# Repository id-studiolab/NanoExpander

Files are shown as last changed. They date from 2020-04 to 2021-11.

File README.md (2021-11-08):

[][cc-by]

# Nano Expander
Grove Breakout board for [Arduino Nano 33 IoT](https://store.arduino.cc/products/arduino-nano-33-iot).

This is the sibling of the [Bitsy Expander](https://github.com/id-studiolab/BitsyExpander), a Grove Breakout board for Adafruit's [ItsyBitsy M4 Express](https://www.adafruit.com/product/3800).

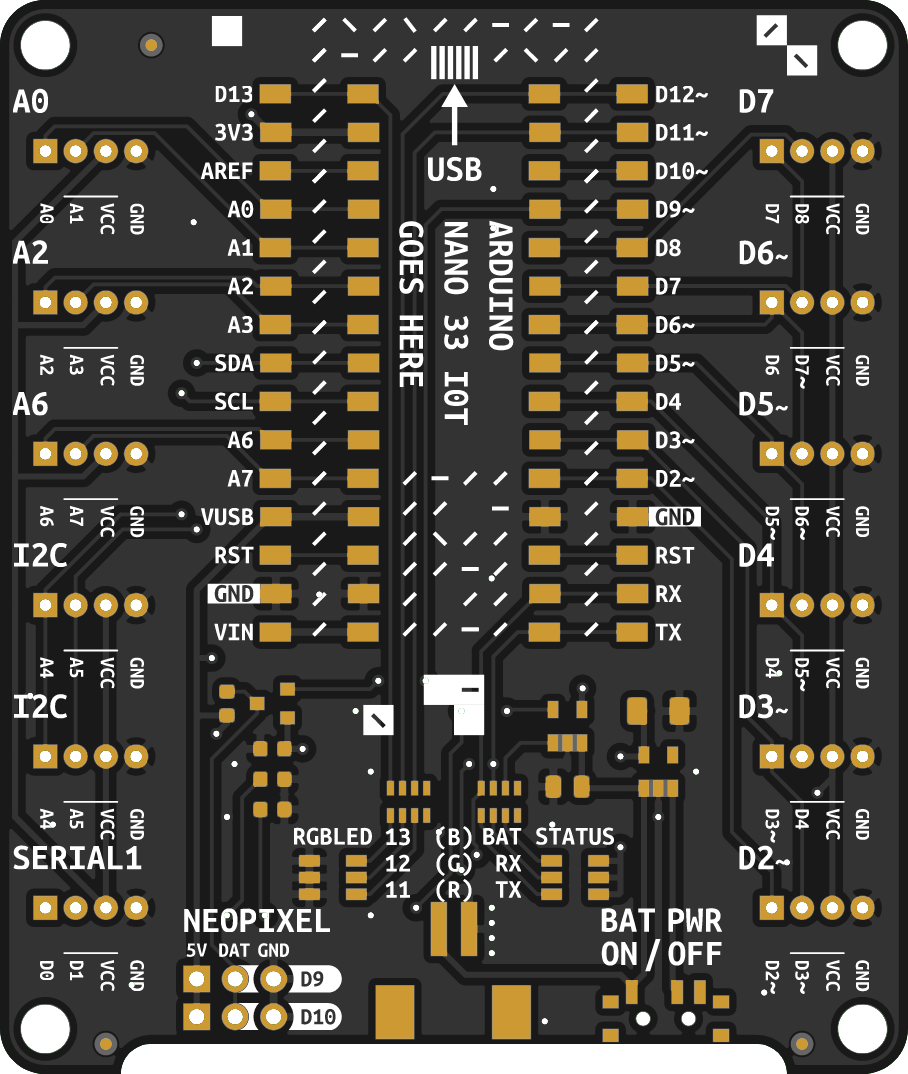
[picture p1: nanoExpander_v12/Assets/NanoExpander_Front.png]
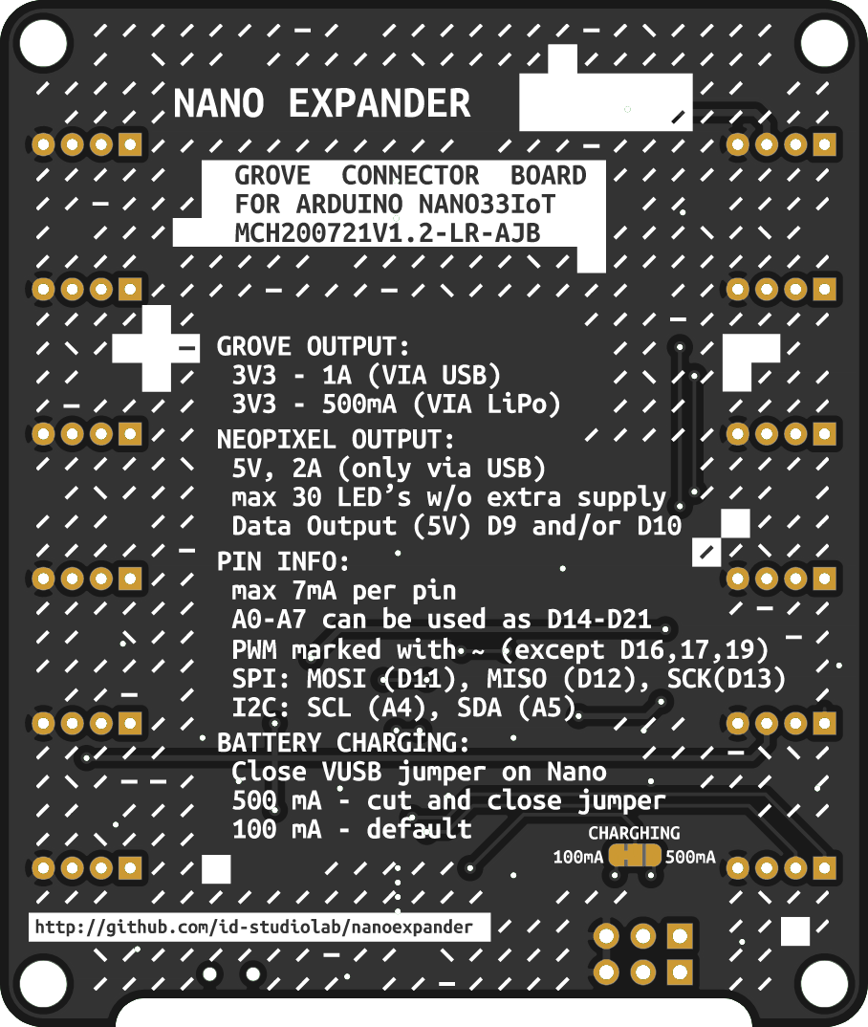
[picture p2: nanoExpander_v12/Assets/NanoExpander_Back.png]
   

This work is licensed under a
[Creative Commons Attribution 4.0 International License][cc-by].

[][cc-by]

[cc-by]: http://creativecommons.org/licenses/by/4.0/
[cc-by-image]: https://i.creativecommons.org/l/by/4.0/88x31.png
[cc-by-shield]: https://img.shields.io/badge/License-CC%20BY%204.0-lightgrey.svg

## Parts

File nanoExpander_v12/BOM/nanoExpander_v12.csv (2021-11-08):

Id | Designator | Package | Quantity | Designation | Supplier and ref
1 | U00 | ARDUINO_NANO_33_IOT_SMD_DUAL_ROW_SOCKET | 1 | ARDUINO_NANO_33_IOT
2 | REF**,REF**,REF** | Fiducial_0.75mm_Dia_1.5mm_Outer | 3 | Fiducial_0.75mm_Dia_1.5mm_Outer
3 | Q00,Q01 | SOT-23 | 2 | BSS138
4 | J13,J14 | PinSocket_1x03_P2.54mm_Vertical | 2 | Conn_01x03
5 | J05,J08,J00,J01,J02,J03,J04,J06,J07,J09,J10,J11 | NS-Tech_Grove_1x04_P2mm_Vertical | 12 | Conn_01x04
6 | C00 | C_0805_2012Metric | 1 | 10uF
7 | C01 | C_1206_3216Metric | 1 | 1uF
8 | J12 | JST_S2B-PH-SM4-TB_LARGE | 1 | Conn_01x02
9 | JP00 | SolderJumper-3_P1.3mm_Bridged12_RoundedPad1.0x1.5mm | 1 | SolderJumper_3_Bridged12
10 | R00,R02,R03 | R_0603_1608Metric | 3 | 10K
11 | R01 | R_0603_1608Metric | 1 | 2K
12 | RN00,RN01 | CAY16-J4 | 2 | 220R
13 | SW00 | SW_SPDT_PCM12 | 1 | ON/OFF
14 | U01 | SOT-23-5 | 1 | MCP73831-2
15 | U03 | SOT-23-5 | 1 | MIC5216
16 | H00,H01,H02,H03 | MountingHole_3.2mm_M3 | 4 | MountingHole
17 | C02,C03 | C_0603_1608Metric | 2 | 100nF
18 | D00,D01 | LED_RGB_PLCC-6 | 2 | LED_BGR

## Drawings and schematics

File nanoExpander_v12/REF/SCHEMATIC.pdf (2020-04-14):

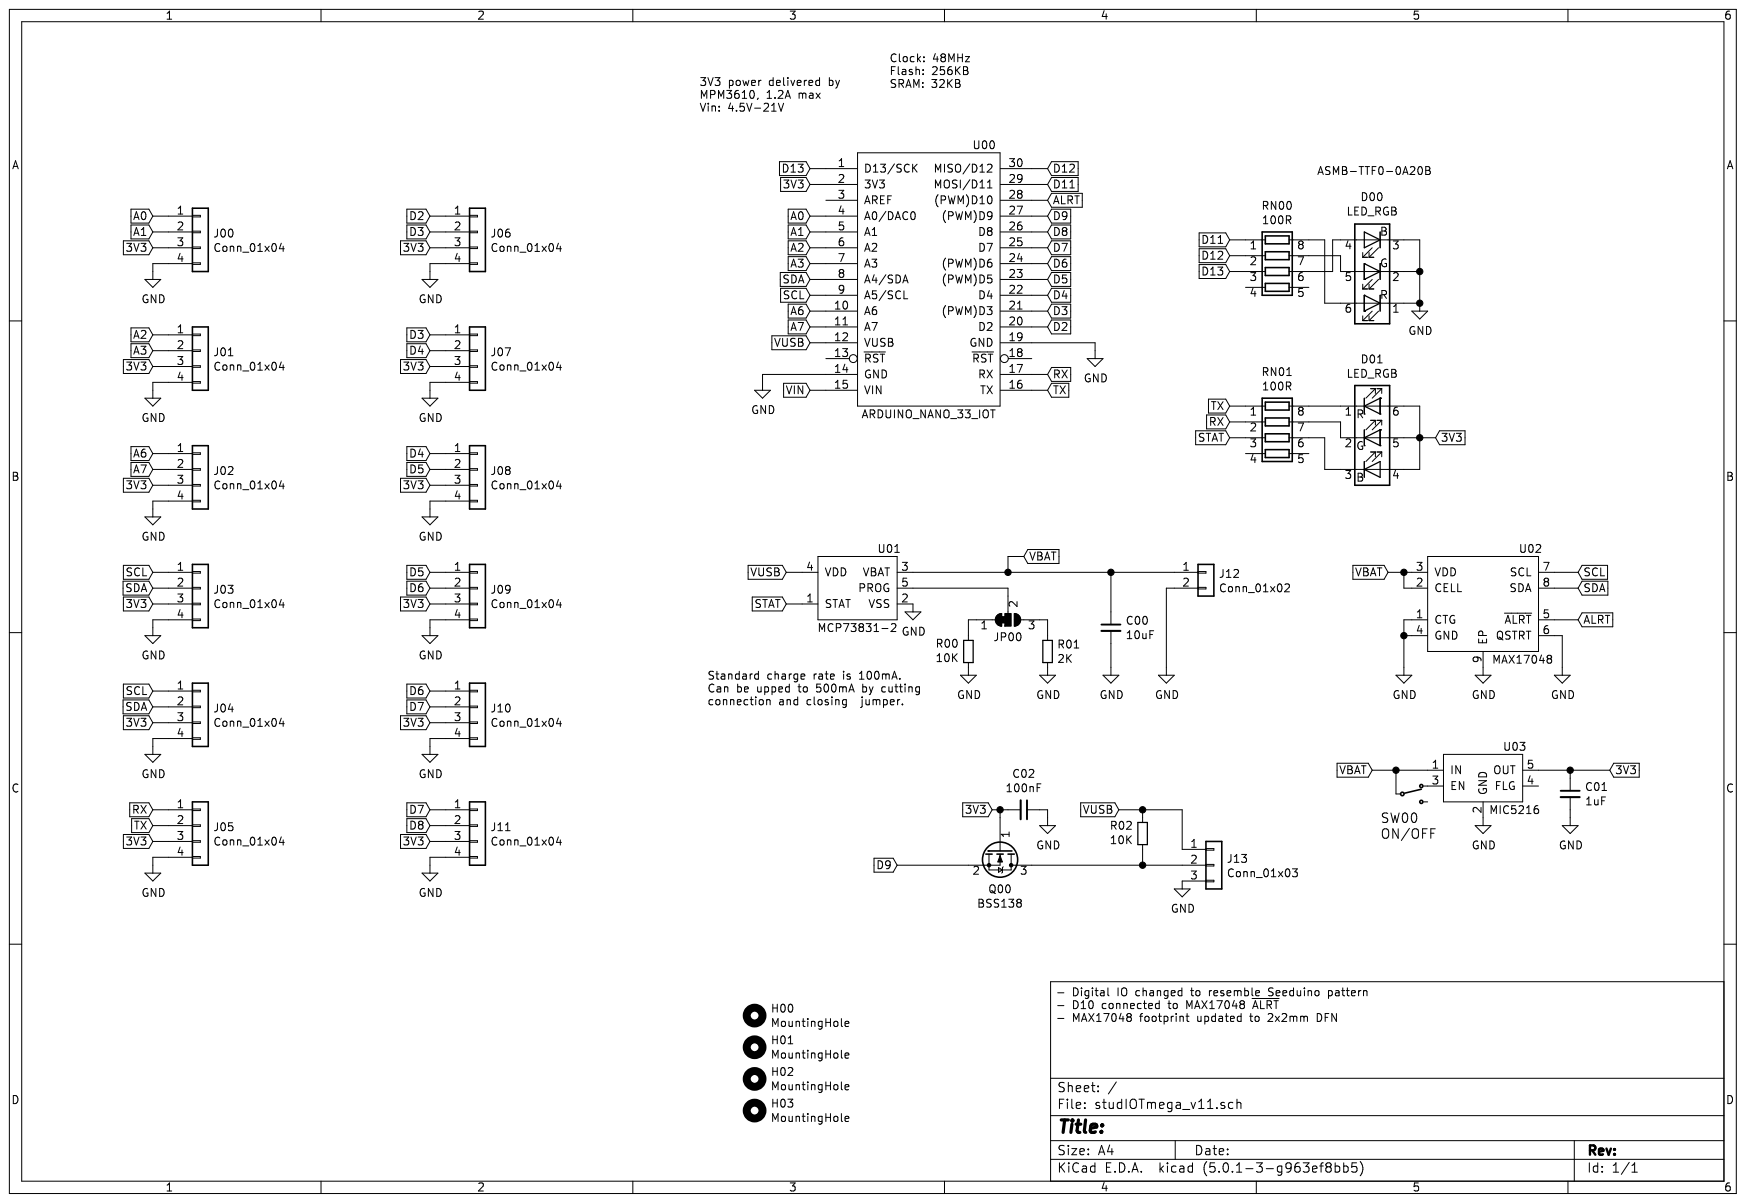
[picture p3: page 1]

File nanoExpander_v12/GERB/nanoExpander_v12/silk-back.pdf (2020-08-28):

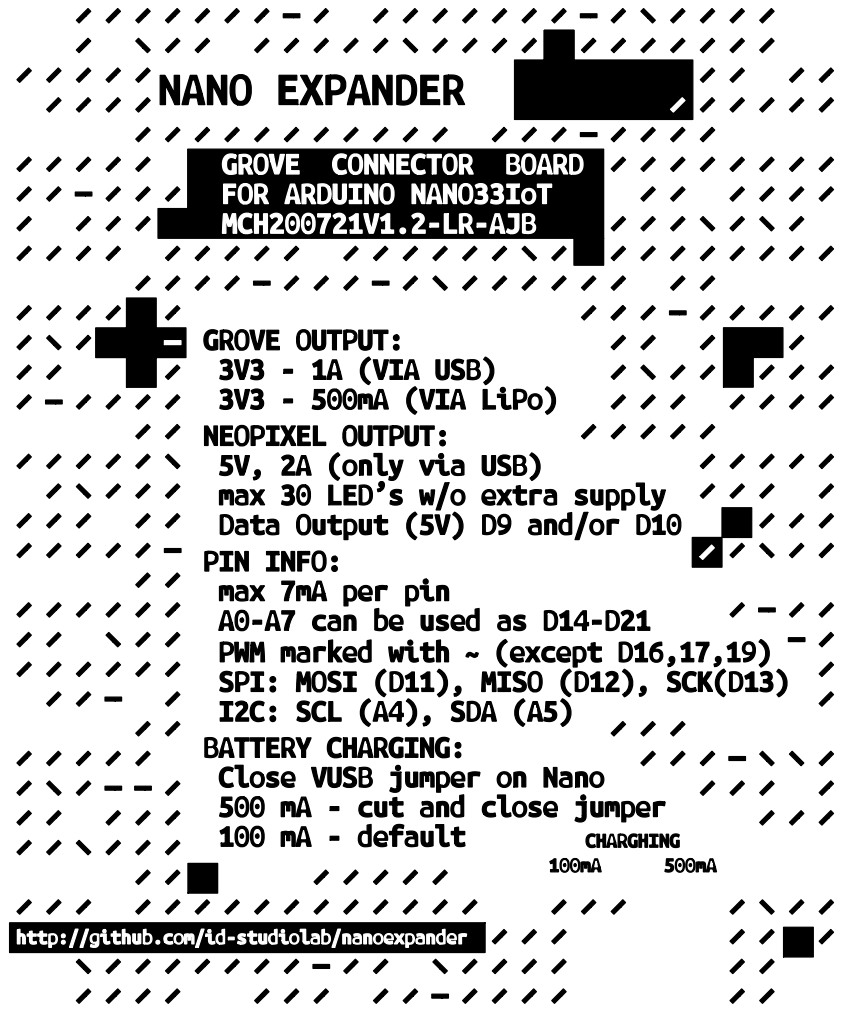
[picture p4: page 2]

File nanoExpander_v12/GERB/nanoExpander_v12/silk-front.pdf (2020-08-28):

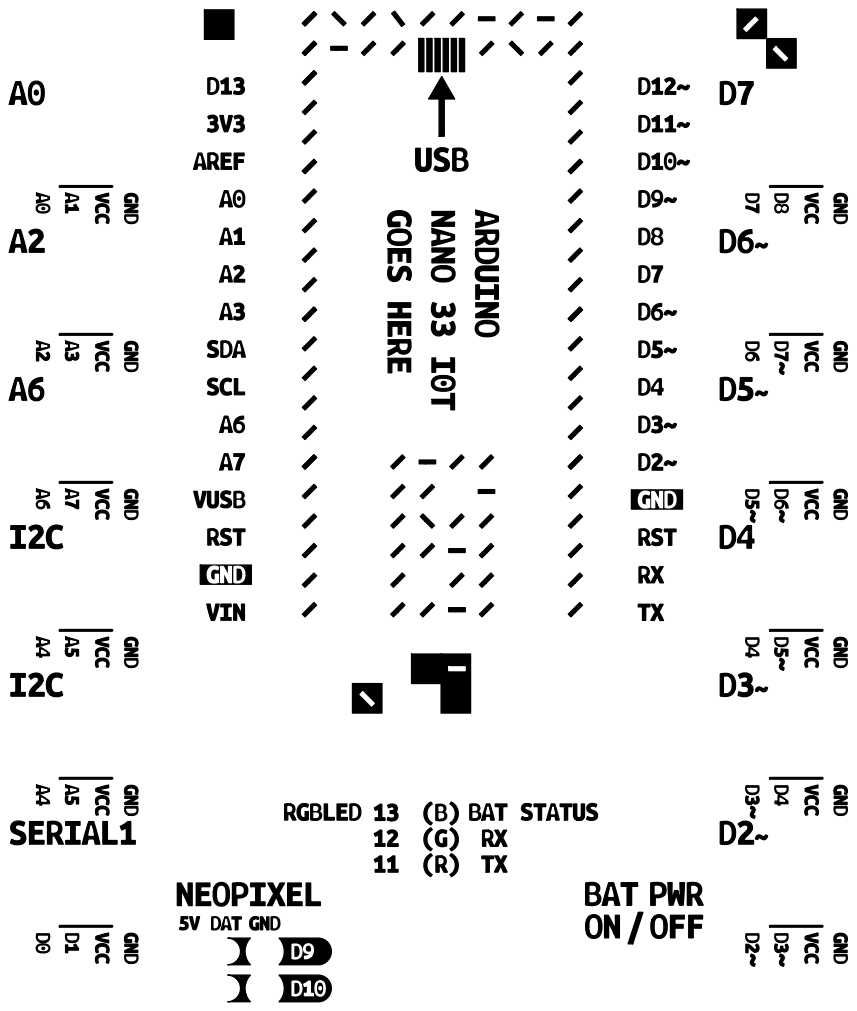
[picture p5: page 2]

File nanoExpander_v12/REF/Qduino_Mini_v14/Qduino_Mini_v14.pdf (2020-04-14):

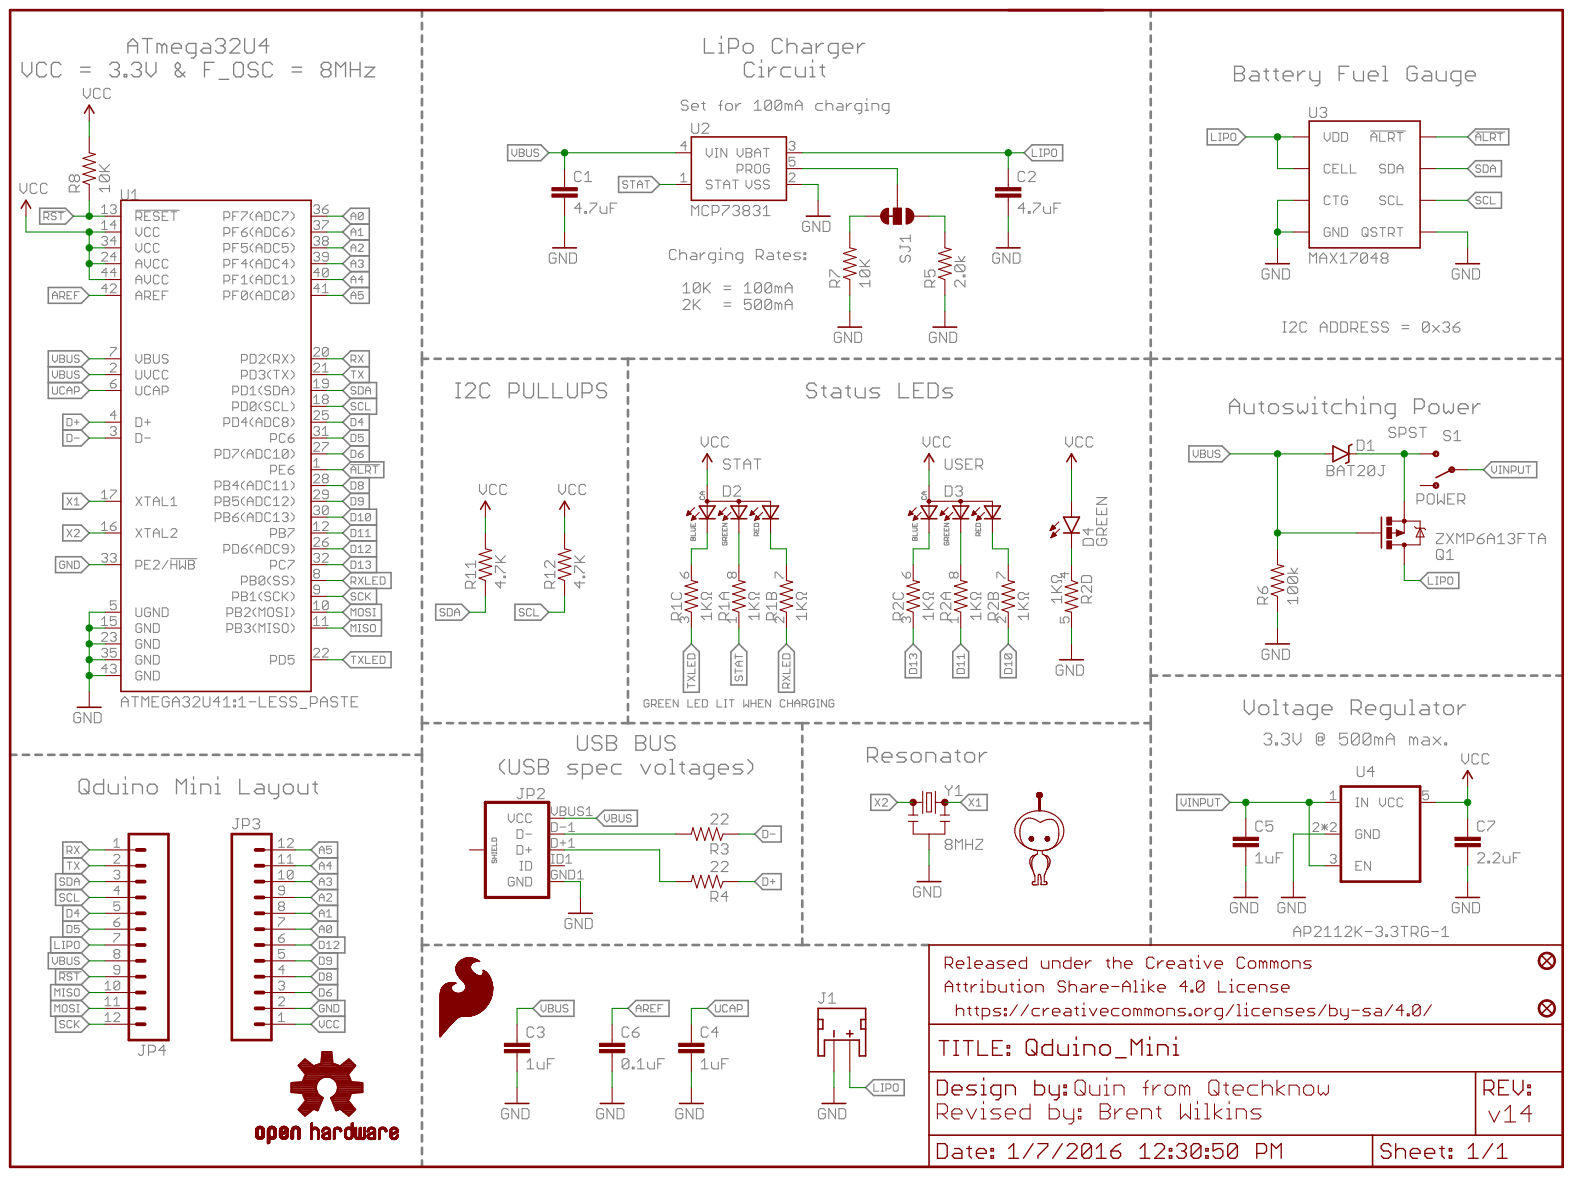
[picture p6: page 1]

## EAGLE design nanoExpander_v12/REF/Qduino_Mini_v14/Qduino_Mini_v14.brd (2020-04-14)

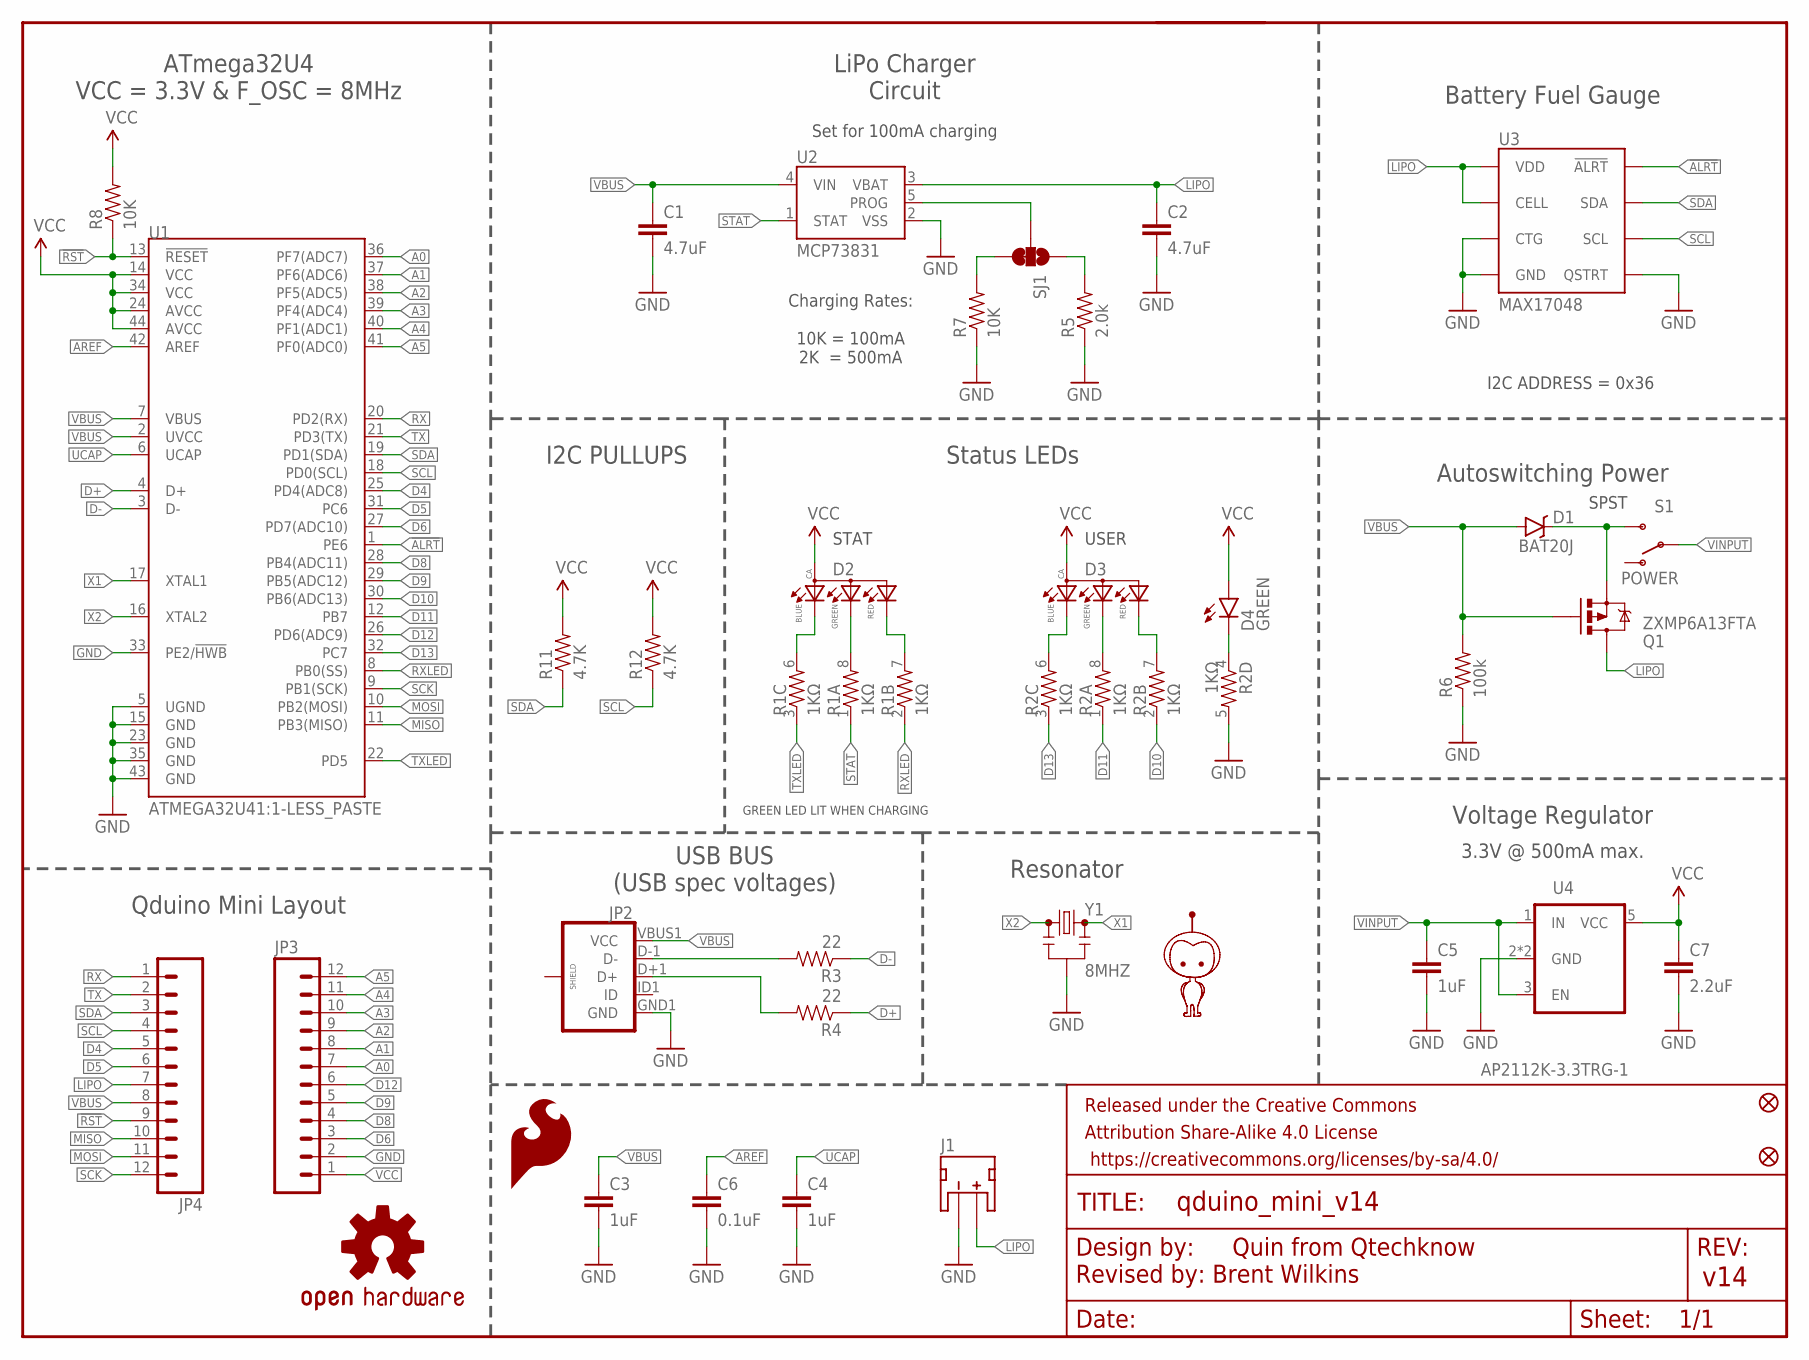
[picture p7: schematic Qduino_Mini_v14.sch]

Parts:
C1, C2: 4.7uF; 0603-CAP
C3, C4, C5: 1uF; 0603-CAP
C6: 0.1uF; 0603-CAP
C7: 2.2uF; 0603-CAP
D1: BAT20J; SOD-323
D2, D3: 0.13_RGB_LEDPLCC; P-LCC-4-3
D4: GREEN; LED-0603
FID1, FID2: FIDUCIALUFIDUCIAL; MICRO-FIDUCIAL
FRAME2: FRAME-LETTER; CREATIVE_COMMONS
J1: LiPo; JST-2-SMD
JP2: USB_MICROB_PLUGCONN-11752; USB-B-MICRO-SMD_V03
JP3, JP4: M12PTH; 1X12
LOGO1: OSHW-LOGOS; OSHW-LOGO-S
LOGO2: SFE_LOGO_FLAME.1_INCH; SFE_LOGO_FLAME_.1
Q1: ZXMP6A13FTA; SOT23-3
R1, R2: 1KΩ; 0603-ARV
R3, R4: 22; 0603-RES
R5: 2.0k; 0603-RES
R6: 100k; 0603-RES
R7, R8: 10K; 0603-RES
R11, R12: 4.7K; 0603-RES
S1: POWER; SWITCH-SPST-SMD-A
SJ1: JUMPER-PAD-3-2OF3_NC_BY_TRACE_SMALL; PAD-JUMPER-3-2OF3_NC_BY_TRACE_YES_SILK_FULL_BOX
U1: ATMEGA32U41:1-LESS_PASTE; QFN-44-NOPAD_1:1-LESS_PASTE
U2: MCP73831; SOT23-5
U3: MAX17048; DFN-8
U4: AP2112K-3.3TRG-1; SOT23-5
U5: MIGHTYQ-L-SILK; LOGO-LARGE-SILK
Y1: 8MHZ; RESONATOR-SMD

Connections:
!ALRT: U1.1 (PE6), U3.P$5 (!ALRT)
!RST: JP4.9, R8.1, U1.13 (!RESET)
A0: JP3.7, U1.36 (PF7(ADC7))
A1: JP3.8, U1.37 (PF6(ADC6))
A2: JP3.9, U1.38 (PF5(ADC5))
A3: JP3.10, U1.39 (PF4(ADC4))
A4: JP3.11, U1.40 (PF1(ADC1))
A5: JP3.12, U1.41 (PF0(ADC0))
AREF: C6.1, U1.42 (AREF)
D4: JP4.5, U1.25 (PD4(ADC8))
D5: JP4.6, U1.31 (PC6)
D6: JP3.3, U1.27 (PD7(ADC10))
D8: JP3.4, U1.28 (PB4(ADC11))
D9: JP3.5, U1.29 (PB5(ADC12))
D10: R2.2 (1), U1.30 (PB6(ADC13))
D11: R2.1, U1.12 (PB7)
D12: JP3.6, U1.26 (PD6(ADC9))
D13: R2.3 (1), U1.32 (PC7)
D+: R4.1, U1.4 (D+)
D-: R3.1, U1.3 (D-)
GND: C1.2, C2.2, C3.2, C4.2, C5.2, C6.2, C7.2, J1.1 (-), JP2.GND1 (GND), JP3.2, R2.5 (2), R5.1, R6.1, R7.1, U1.5 (UGND), U1.15 (GND), U1.23 (GND), U1.33 (PE2/!HWB), U1.35 (GND), U1.43 (GND), U2.2 (VSS), U3.P$1 (CTG), U3.P$4 (GND), U3.P$6 (QSTRT), U3.P$9 (GND), U4.2 (GND), U4.4 (GND), Y1.2
INMOSFET: D1.C, Q1.2 (S), S1.3 (S)
LIPO: C2.1, J1.2 (+), JP4.7, Q1.3 (D), U2.3 (VBAT), U3.P$2 (CELL), U3.P$3 (VDD)
MISO: JP4.10, U1.11 (PB3(MISO))
MOSI: JP4.11, U1.10 (PB2(MOSI))
unnamed: D2.3 (BLUE), R1.6 (2)
unnamed: D2.2 (GREEN), R1.8 (2)
unnamed: D3.3 (BLUE), R2.6 (2)
unnamed: D4.C, R2.4 (1)
unnamed: R7.2, SJ1.3
unnamed: R5.2, SJ1.1
unnamed: D3.2 (GREEN), R2.8 (2)
unnamed: D2.1 (RED), R1.7 (2)
unnamed: D3.1 (RED), R2.7 (2)
PROG: SJ1.2, U2.5 (PROG)
RX: JP4.1, U1.20 (PD2(RX))
RXLED: R1.2 (1), U1.8 (PB0(SS))
SCK: JP4.12, U1.9 (PB1(SCK))
SCL: JP4.4, R12.1, U1.18 (PD0(SCL)), U3.P$7 (SCL)
SDA: JP4.3, R11.1, U1.19 (PD1(SDA)), U3.P$8 (SDA)
STAT: R1.1, U2.1 (STAT)
TX: JP4.2, U1.21 (PD3(TX))
TXLED: R1.3 (1), U1.22 (PD5)
UCAP: C4.1, U1.6 (UCAP)
UD+: JP2.D+1 (D+), R4.2
UD-: JP2.D-1 (D-), R3.2
VBUS: C1.1, C3.1, D1.A, JP2.VBUS1 (VCC), JP4.8, Q1.1 (G), R6.2, U1.2 (UVCC), U1.7 (VBUS), U2.4 (VIN)
VCC: C7.1, D2.4 (ANODE), D3.4 (ANODE), D4.A, JP3.1, R8.2, R11.2, R12.2, U1.14 (VCC), U1.24 (AVCC), U1.34 (VCC), U1.44 (AVCC), U4.5 (VCC)
VINPUT: C5.1, S1.2, U4.1 (IN), U4.3 (EN)
X1: U1.17 (XTAL1), Y1.3
X2: U1.16 (XTAL2), Y1.1

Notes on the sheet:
Set for 100mA charging
USB BUS (USB spec voltages)
Resonator
Status LEDs
3.3V @ 500mA max.
SPST
ATmega32U4 VCC = 3.3V & F_OSC = 8MHz
Qduino Mini Layout
LiPo Charger Circuit
Battery Fuel Gauge
Voltage Regulator
Autoswitching Power
Charging Rates: 10K = 100mA 2K = 500mA
I2C PULLUPS
Revised by: Brent Wilkins
I2C ADDRESS = 0x36
USER
STAT
GREEN LED LIT WHEN CHARGING

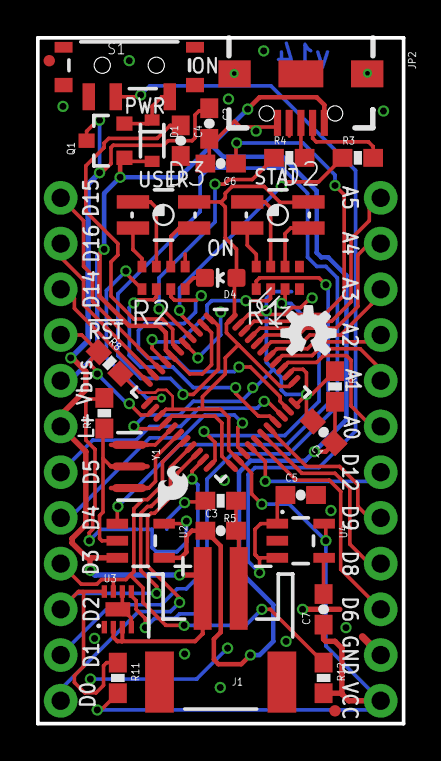
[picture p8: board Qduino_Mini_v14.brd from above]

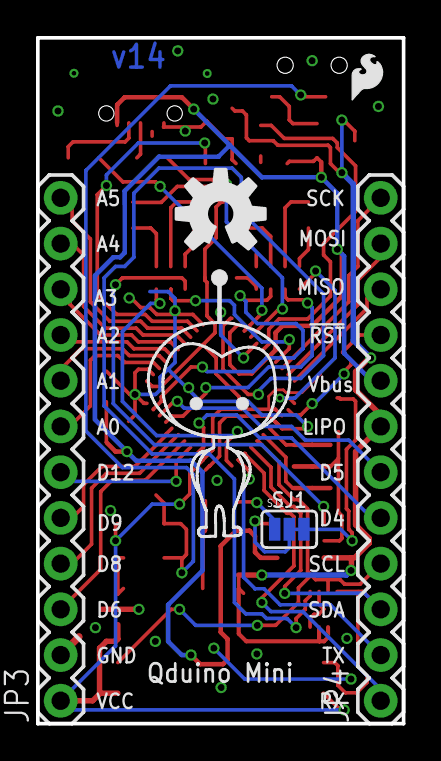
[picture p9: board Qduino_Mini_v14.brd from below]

Board: 2 copper layers, 20.3 x 38.1 mm, 41 parts (6 on the bottom side), 51 nets.

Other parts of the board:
LOGO3: SFE_LOGO_FLAME.1_INCH; SFE_LOGO_FLAME_.1@1
U$4: OSHW-LOGO-M@1

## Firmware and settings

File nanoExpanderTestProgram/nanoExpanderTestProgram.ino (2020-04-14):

// NANO expander test program.
// for testing HV1.1
// 20200409MCH

#define RED 11
#define GRN 12
#define BLU 13

//#include "libs/Adafruit_NeoPixel/Adafruit_NeoPixel.h"
#include <Adafruit_NeoPixel.h>

#define LED_PIN    8

#define LED_COUNT 10

// Declare our NeoPixel strip object:
Adafruit_NeoPixel strip(LED_COUNT, LED_PIN, NEO_GRB + NEO_KHZ800);
// Argument 1 = Number of pixels in NeoPixel strip
// Argument 2 = Arduino pin number (most are valid)
// Argument 3 = Pixel type flags, add together as needed:
//   NEO_KHZ800  800 KHz bitstream (most NeoPixel products w/WS2812 LEDs)
//   NEO_KHZ400  400 KHz (classic 'v1' (not v2) FLORA pixels, WS2811 drivers)
//   NEO_GRB     Pixels are wired for GRB bitstream (most NeoPixel products)
//   NEO_RGB     Pixels are wired for RGB bitstream (v1 FLORA pixels, not v2)
//   NEO_RGBW    Pixels are wired for RGBW bitstream (NeoPixel RGBW products)

#include "libs/MAX17048/MAX17048.h" 

MAX17048 pwr_mgmt;

void setup() {

  pinMode( 11, OUTPUT );
  pinMode( 12, OUTPUT );
  pinMode( 13, OUTPUT );

  pinMode(2, INPUT_PULLUP);
  pinMode(3, INPUT_PULLUP);
  pinMode(4, INPUT_PULLUP);
  pinMode(5, INPUT_PULLUP);
  pinMode(6, INPUT_PULLUP);
  pinMode(7, INPUT_PULLUP);
  pinMode(8, INPUT_PULLUP);
  
  Serial.begin(9600);
  while(!Serial){}
  
  Serial.println("test program for NANO epander board");
  Serial.println("hardware version 1.1");
  Serial.println("...");
  delay(2000);
  
  Serial.println("status LED testing");
  Serial.println("...");
  delay(2000);
  
  Serial.print("RED (D11) blinking");
  blinkLED(RED);
  Serial.println("");
  Serial.print("GREEN (D12) blinking");
  blinkLED(GRN);
  Serial.println("");
  Serial.print("BLUE (D13) blinking");
  blinkLED(BLU);
  Serial.println("");

  Serial.println("...");

  delay(2000);
  Wire.begin();
  pwr_mgmt.attatch(Wire);
  Serial.println("fuel gauge testing");
  Serial.println("...");
  delay(2000);
  Serial.print("VCELL ADC : ");
  Serial.println(pwr_mgmt.adc());
  Serial.print("VCELL V   : ");
  Serial.println(pwr_mgmt.voltage());
  Serial.print("VCELL SOC : ");
  Serial.print(pwr_mgmt.percent());
  Serial.println(" \%");
  Serial.print("VCELL SOC : ");
  Serial.print(pwr_mgmt.accuratePercent());
  Serial.println(" \%");
 
  Serial.println("...");
  delay(2000);

  Serial1.begin(9600);
  Serial.println("printing \"Hello, world!\" to Serial1");
  delay(1000);
  Serial1.println("Hello, world!");
  delay(1000);
  Serial1.println("Hello, world!");
  delay(1000);
  Serial.println("...");
  delay(1000);  
  Serial.println("neopixel strandtest");
  strip.begin();           // INITIALIZE NeoPixel strip object (REQUIRED)
  strip.show();            // Turn OFF all pixels ASAP
  strip.setBrightness(50); // Set BRIGHTNESS to about 1/5 (max = 255)
  
  colorWipe(strip.Color(255,   0,   0), 50); // Red
  colorWipe(strip.Color(  0, 255,   0), 50); // Green
  colorWipe(strip.Color(  0,   0, 255), 50); // Blue

  Serial.println("...");
  delay(2000);
  
  Serial.println("input testing");
  Serial.println("digital inputs have pullup");
  Serial.println("D2 LOW to continue");
  Serial.println("[D2][D3][D4][D5][D6][D7] [A0] [A2] [A4] [A6]");
  delay(3000);
  Serial.println("...");
  readPorts();
  Serial.println("...");

  
  
  
  
}

void readPorts(){
 
  
  //while(! digitalRead(2) ){
    while(1){
    for(int i = 2; i < 8; i++){
      Serial.print(digitalRead(i));
    }
    Serial.print(" ");
    Serial.print(analogRead(A0));
    Serial.print(" ");
    Serial.print(analogRead(A2));
    Serial.print(" ");
    Serial.print(analogRead(A4));
    Serial.print(" ");
    Serial.print(analogRead(A6));
    
    Serial.println("");
    
    if(digitalRead(2) ==  0 ){
      break;
    }
    delay(200);
    
  }
   
}

void blinkLED( uint8_t LED ){
  for(int i = 2; i>0; i--){
    digitalWrite( LED, HIGH );
    Serial.print(".");
    delay(500);
    digitalWrite( LED, LOW );
    Serial.print(".");
    delay(500);
  }
}

void colorWipe(uint32_t color, int wait) {
  for(int i=0; i<strip.numPixels(); i++) { // For each pixel in strip...
    strip.setPixelColor(i, color);         //  Set pixel's color (in RAM)
    strip.show();                          //  Update strip to match
    delay(wait);                           //  Pause for a moment
  }
}
    
void loop() {

  
  // put your main code here, to run repeatedly:

}

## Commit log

2020-04-14 V1.1 files
    [Qduino_Mini_v14.brd, Qduino_Mini_v14.sch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]
2021-11-08 BOM added
    [nanoExpander_v12.csv]

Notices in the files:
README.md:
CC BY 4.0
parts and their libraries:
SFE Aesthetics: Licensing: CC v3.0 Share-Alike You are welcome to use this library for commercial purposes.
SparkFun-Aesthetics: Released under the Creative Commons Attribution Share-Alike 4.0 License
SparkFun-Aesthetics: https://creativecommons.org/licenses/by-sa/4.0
